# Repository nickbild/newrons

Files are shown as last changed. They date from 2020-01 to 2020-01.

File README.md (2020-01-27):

# Newrons

Give your memory a boost with Newrons.

<p align="center">
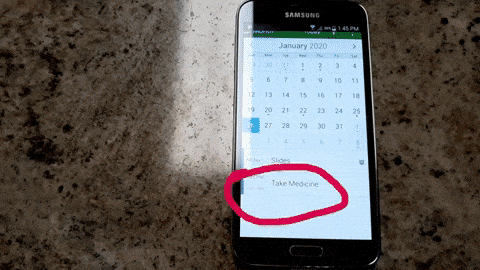
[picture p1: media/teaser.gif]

</p>

Higher resolution video in [Media](https://github.com/nickbild/newrons#media) section below.

Newrons are smart glasses that offer a gentle memory assist by flashing a light in the wearer's peripheral vision when they are in the vicinity of an object associated with an event on their calendar.  For example, if the user has "Take Medicine" on their calendar at 2:00PM, and they are near a pill bottle around that time, a light on the glasses will flash to jog the wearer's memory.

This offers the advantage of reminding the wearer of something they need to do exactly when it is convenient to do so.  Smartphone notifications can often be dismissed and forgotten because they give an alert at a time when they are inconvenient or impossible to immediately act on.  It is also completely passive and doesn't require one to have their phone at hand.

## How It Works

A pair of glasses is fitted with a JeVois A33 Smart Machine Vision Camera, an Arduino Nano 33 IoT, an Adafruit PCF8523 Real Time Clock, and a 5050 RGB LED.  Power is supplied by a 5V battery pack.

The JeVois is configured to run a TensorFlow deep convolutional neural network trained on the ImageNet dataset for object detection.  Real-time information about detected objects is transmitted via the 4-pin serial interface to the Arduino.

The Arduino connects via WiFi to the Google Calendar API and retrieves events for the current day using information from the real time clock.  When an object is detected that is associated with a calendar event, within a specified window of time around that event, an LED is pulsed.  [Arduino Code](https://github.com/nickbild/newrons/blob/master/newrons_controller/newrons_controller.ino)

## Media

See it in action:
[YouTube](https://www.youtube.com/watch?v=C8D3Lubc3Jo)

Top view:
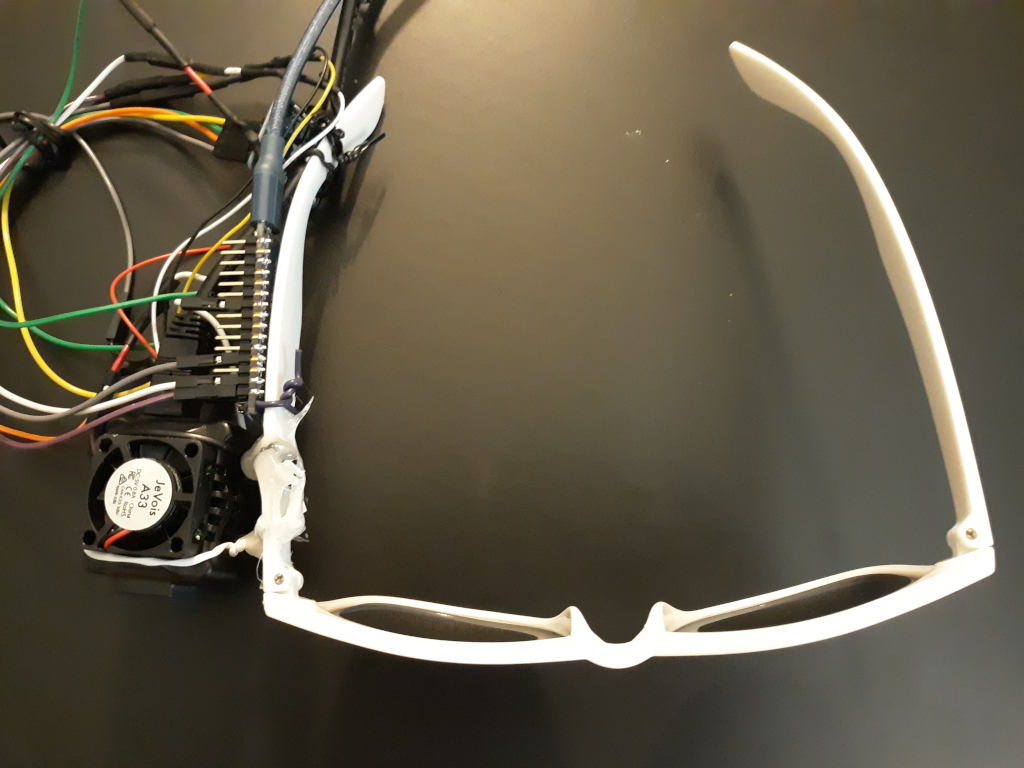
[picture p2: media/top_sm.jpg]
top


Front view:
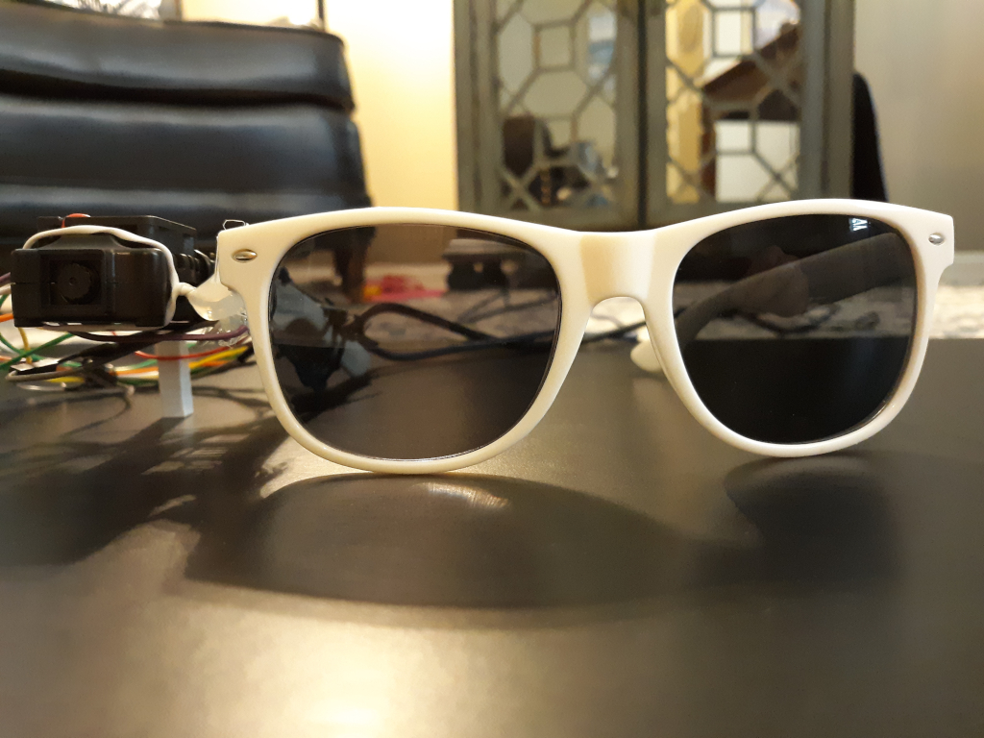
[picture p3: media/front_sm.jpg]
front


Front left view:
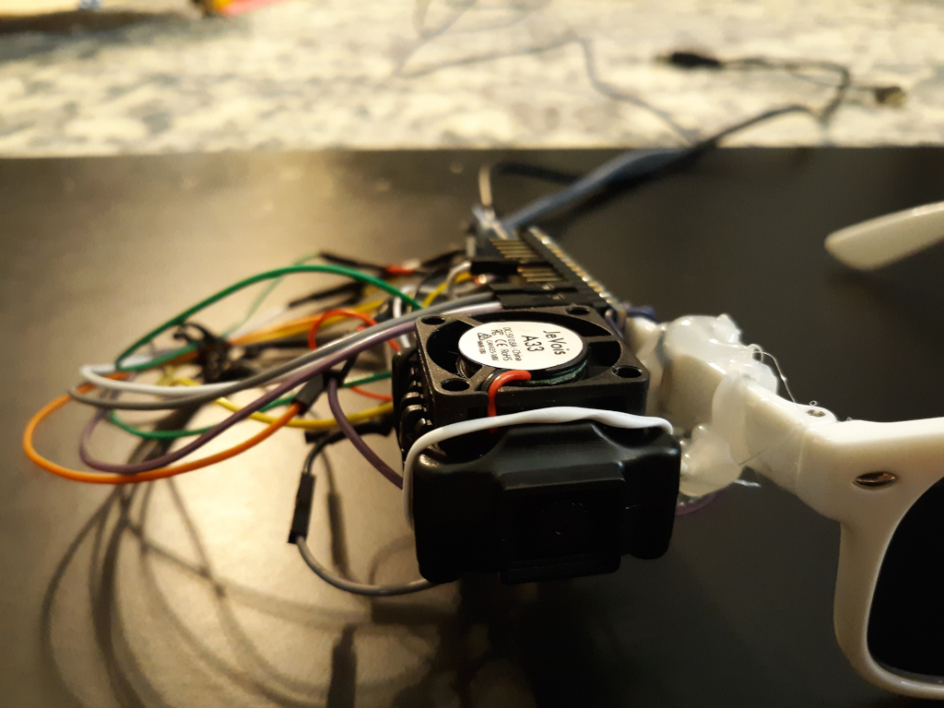
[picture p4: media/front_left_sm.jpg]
front left


Front left angle view:
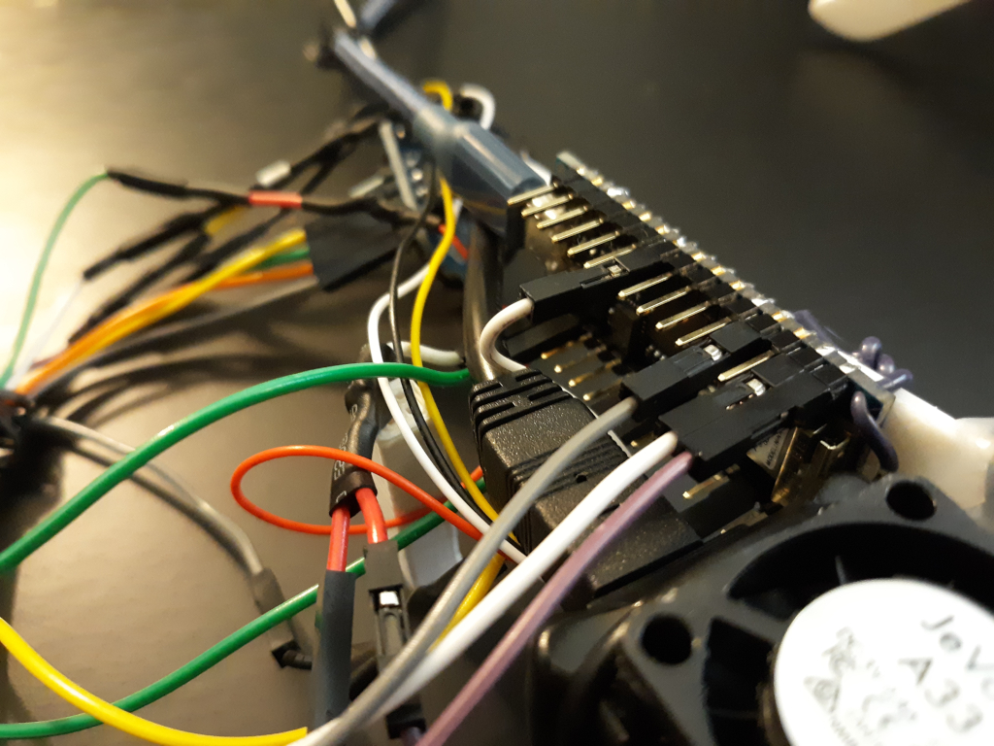
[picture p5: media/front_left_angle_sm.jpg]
front left angle


Side angle view:
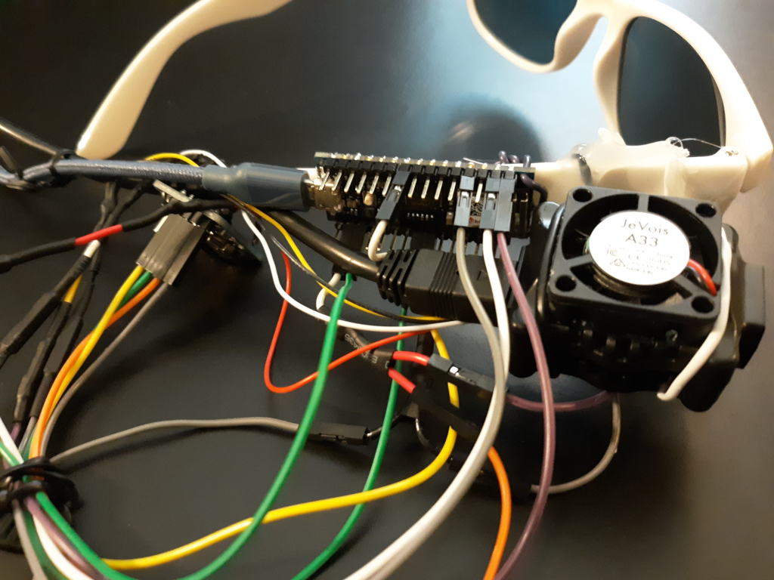
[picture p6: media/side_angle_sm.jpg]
Side angle


## Circuit Diagram

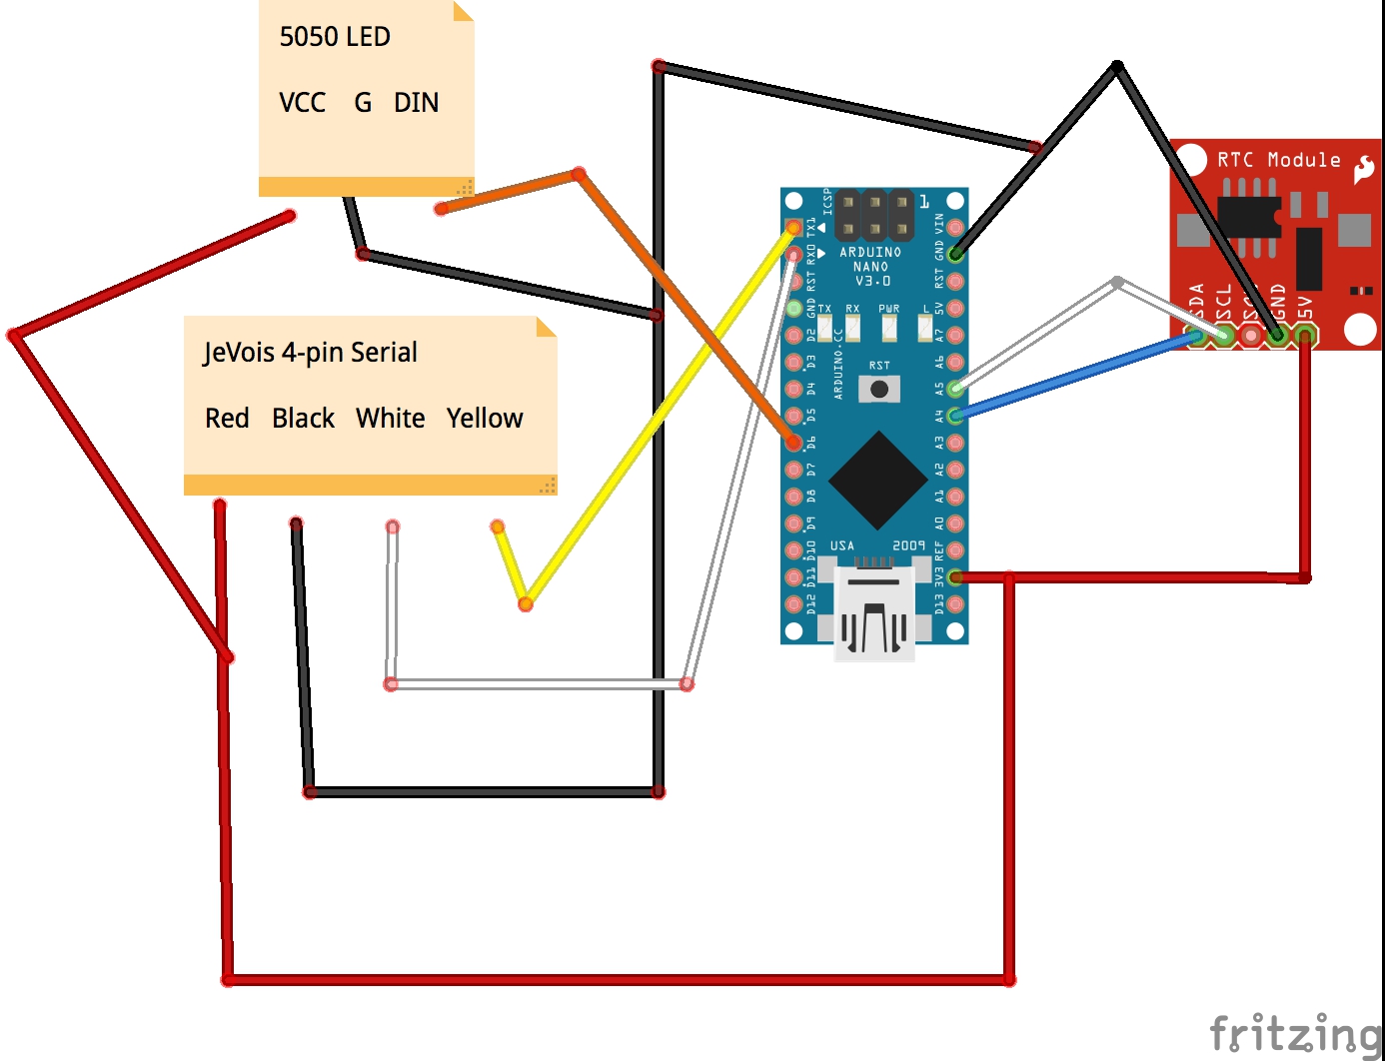
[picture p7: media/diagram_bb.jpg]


## Bill of Materials

- JeVois A33 Smart Machine Vision Camera
- Arduino Nano 33 IoT
- Adafruit PCF8523 Real Time Clock
- 5050 RGB LED
- 5V battery pack
- Glasses or sunglasses

## About the Author

[Nick A. Bild, MS](https://nickbild79.firebaseapp.com/#!/)

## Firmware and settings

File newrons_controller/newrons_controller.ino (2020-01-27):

#include "secret.h"
#include "RTClib.h"
#include <Adafruit_NeoPixel.h>
#include <SPI.h>
#include <WiFiNINA.h>
#include <ArduinoJson.h>

#define INLEN 256
char instr[INLEN + 1];

Adafruit_NeoPixel pixels(1, 6, NEO_GRB + NEO_KHZ800);
RTC_PCF8523 rtc;

char ssid[] = SECRET_SSID;
char pass[] = SECRET_PASS;
int status = WL_IDLE_STATUS;

WiFiClient client;
char server[] = "www.googleapis.com";
int startSaving = 0;
String apiResult;

StaticJsonDocument<8000> doc;
int jsonParsed = 0;

int takeMeds = 0;
int goWalk = 0;
int makeLunch = 0;

void setup() {
  // USB.
  Serial.begin(115200);

  // JeVois device.
  Serial1.begin(115200);
  Serial1.setTimeout(500);

  // PCF8523 real-time clock.
  rtc.begin();

  // Get current date/time.
  DateTime now = rtc.now();
  //rtc.adjust(DateTime(F(__DATE__), F(__TIME__)));   // Run once to initialize clock.

  // Connect to WiFi.
  while (status != WL_CONNECTED) {
    Serial.print("Attempting to connect to WPA SSID: ");
    Serial.println(ssid);
    status = WiFi.begin(ssid, pass);
    
    // Wait 10 seconds for connection.
    delay(10000);
  }
  Serial.println("Connected to network.");

  // Get Google calendar events.
  DateTime minDT (now - TimeSpan(0, 1, 0, 0));
  String minTime = String(minDT.year()) + "-" + String(minDT.month()) + "-" + String(minDT.day()) + "T" + String(minDT.hour()) + ":" + String(minDT.minute()) + ":" + String(minDT.second()) + "-05:00";
  DateTime maxDT (now + TimeSpan(0, 1, 0, 0));
  String maxTime = String(maxDT.year()) + "-" + String(maxDT.month()) + "-" + String(maxDT.day()) + "T" + String(maxDT.hour()) + ":" + String(maxDT.minute()) + ":" + String(maxDT.second()) + "-05:00";
  
  String apiUrl = "/calendar/v3/calendars/" EMAIL_ADDRESS "/events?access_token=" ACCESS_TOKEN "&timeMin=" + minTime + "&timeMax=" + maxTime;

  if (client.connectSSL(server, 443)) {
    Serial.println("Connected to server.");
    client.println("GET " + apiUrl + " HTTP/1.1");
    client.println("Host: www.googleapis.com");
    client.println("Connection: close");
    client.println();
  }

  // 5050 LED
  pinMode(6, OUTPUT);
  pixels.begin();

  flashLED();
}

void loop() {
  while (client.available()) {
    char c = client.read();
    if (c == '{') {
      startSaving = 1;
    }

    if (startSaving) {
      apiResult += c;
    }
  }

  // Parse JSON.
  if (jsonParsed == 0 && apiResult != "") {
    DeserializationError error = deserializeJson(doc, apiResult);
  
    if (error) {
      Serial.print(F("deserializeJson() failed: "));
      Serial.println(error.c_str());
    }
    
    jsonParsed = 1;
  }

  if (jsonParsed == 1) {
    JsonArray items = doc["items"];
    for (int i=0; i<items.size(); i++) {
      const char* summary = items[i]["summary"];
      Serial.println(summary);

      if (String(summary).indexOf("Take Medicine") > -1) {
        takeMeds = 1;
      } else if (String(summary).indexOf("Go for a walk")) {
        goWalk = 1;
      } else if (String(summary).indexOf("Make Lunch")) {
        makeLunch = 1;
      }

    }

    jsonParsed = 2;
  }
  
  // Read a line of data from JeVois:
  byte len = Serial1.readBytesUntil('\n', instr, INLEN);

  // Make sure the string is null-terminated:
  instr[len--] = '\0';

  // Cleanup any trailing whitespace:
  while (len >= 0 && instr[len] == ' ' || instr[len] == '\r' || instr[len] == '\n') instr[len--] = '\0';

  if (String(instr).startsWith("DO ")) {
    Serial.println(instr);

    if (String(instr).indexOf("pill_bottle") > -1 && takeMeds) {
      flashLED();
    } else if (String(instr).indexOf("microwave") > -1 && makeLunch) {
      flashLED();
    } else if ((String(instr).indexOf("running_shoe") > -1 || String(instr).indexOf("Loafer") > -1) && goWalk) {
      flashLED();
    }

  }

}

void flashLED() {
  for (int i=1; i<151; i++) {
    pixels.setPixelColor(0, pixels.Color(0, 0, i));
    pixels.show();
    delay(12);
  }
  
  for (int i=149; i>=0; i--) {
    pixels.setPixelColor(0, pixels.Color(0, 0, i));
    pixels.show();
    delay(12);
  }
}

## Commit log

2020-01-18 Track changes to JeVois config.
    [initscript.cfg]
2020-01-25 Add indicator RGB LED.
2020-01-27 Smooth LED flashing.
2020-01-27 Add circuit diagram.
    [diagram.fzz]
